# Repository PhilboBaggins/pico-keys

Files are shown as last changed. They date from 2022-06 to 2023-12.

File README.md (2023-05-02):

PicoKeys
========

A small macro keyboard using a [RPi Pico](https://www.raspberrypi.com/products/raspberry-pi-pico/). Originally made to help someone that had been in a car accident and had (hopefully temporary) limited use of her fingers. The original problem was that her work laptop required pressing CTRL-ALT-DELETE to login, which she couldn't do with only 2 working fingers. This board solved that with 1 key and left 15 more for other conveniences.

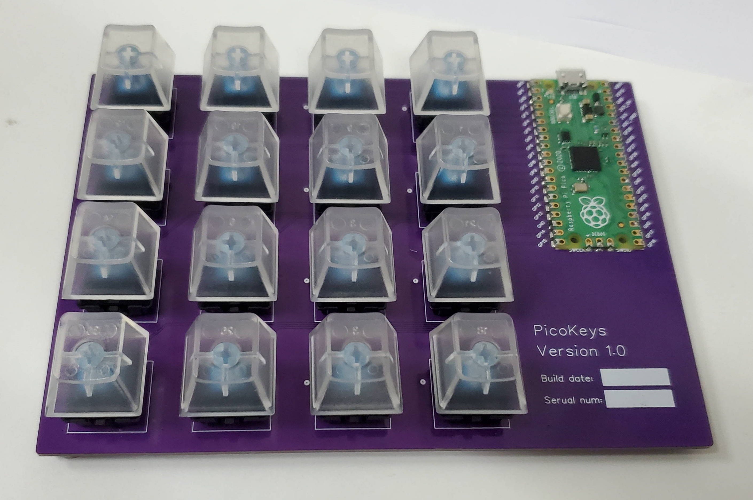
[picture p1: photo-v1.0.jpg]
Photo of assembled v1.0 board

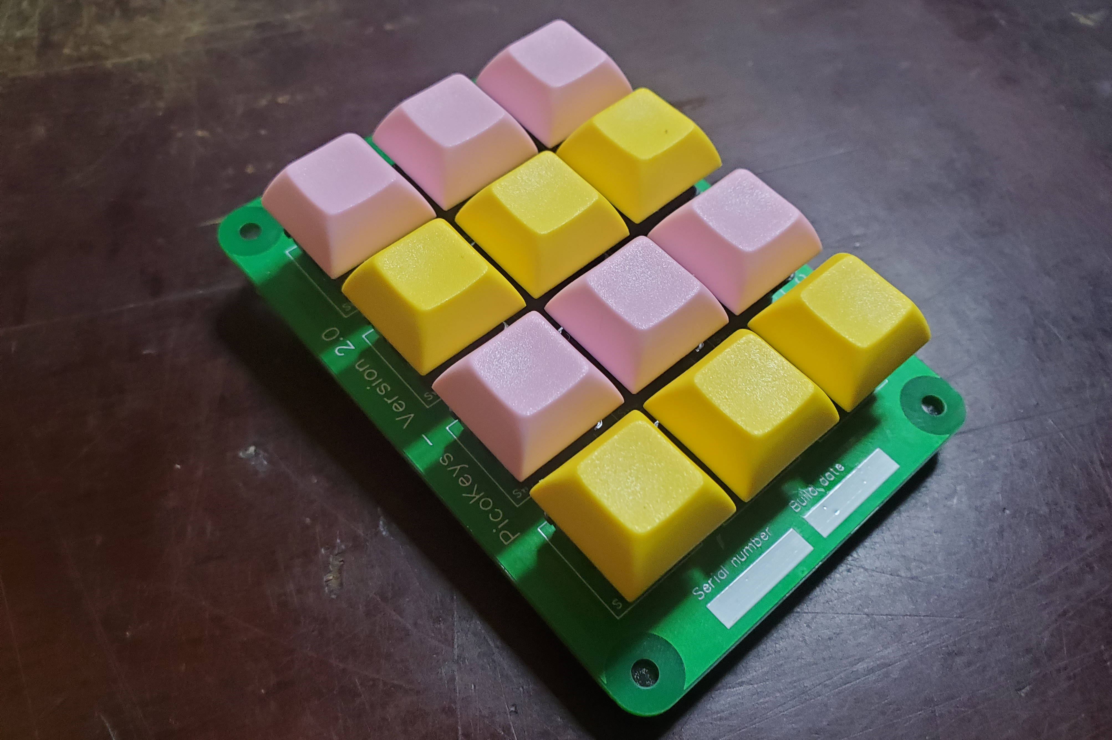
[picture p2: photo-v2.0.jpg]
Photo of assembled v2.0 board


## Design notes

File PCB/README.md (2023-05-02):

PicoKey PCB
===========

A small macro keyboard using a [RPi Pico](https://www.raspberrypi.com/products/raspberry-pi-pico/).

| Version 1.0 | Version 2.0 |
| --- | --- |
| Top of v1.0 board | Top of v2.0 board |
| Bottom of v1.0 board | Bottom of v2.0 board |
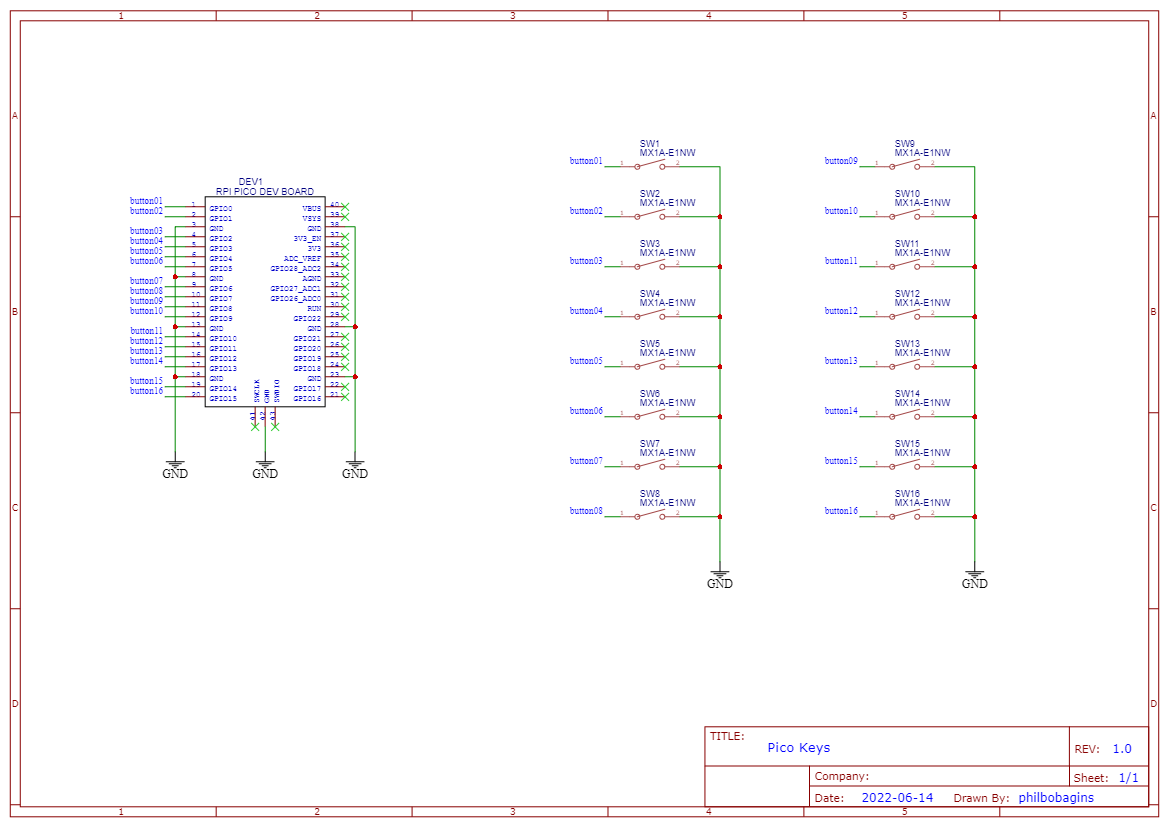
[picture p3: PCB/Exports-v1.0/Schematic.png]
Schematic for v1.0 board
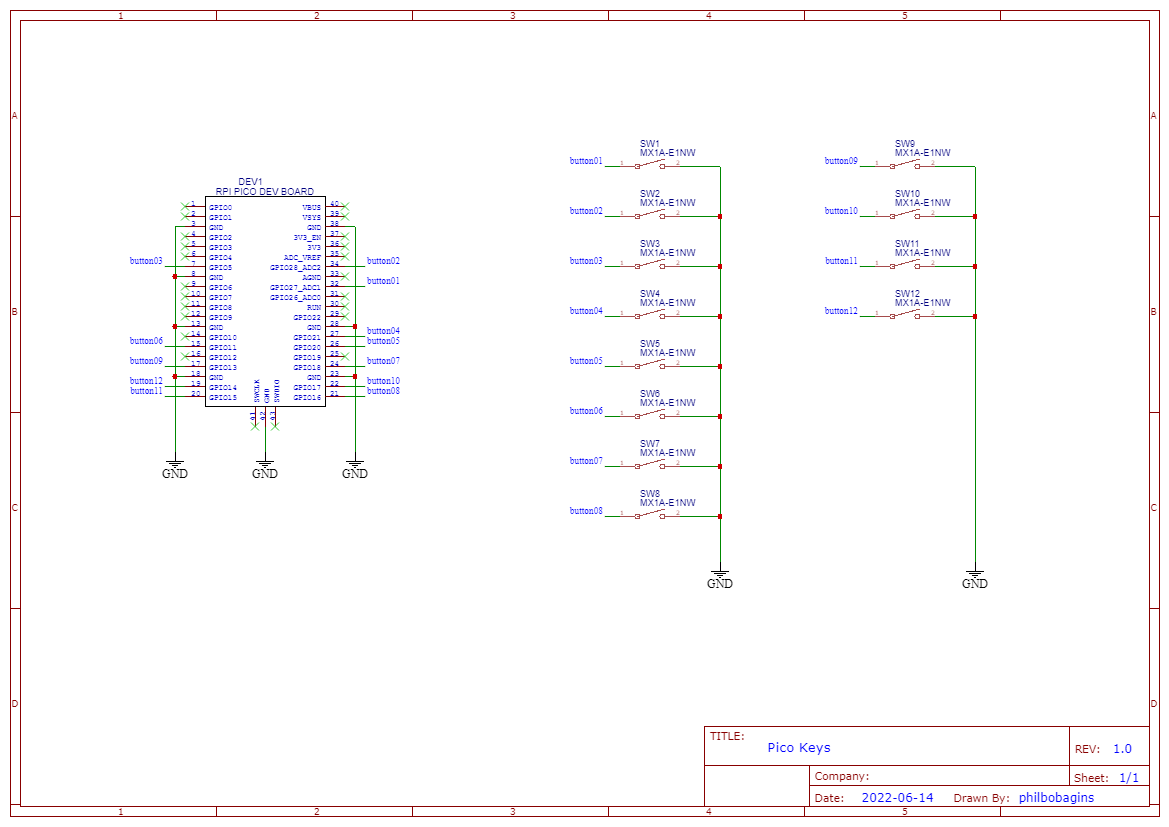
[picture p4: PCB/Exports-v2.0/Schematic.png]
Schematic for v2.0 board
|  |  |
| Photo of assembled v1.0 board | Photo of assembled v2.0 board |

Components
----------

The standard RPi Pico:

* Official website: <https://www.raspberrypi.com/products/raspberry-pi-pico/>
* DigiKey: <https://www.digikey.com/en/products/detail/raspberry-pi/SC0915/13624793>

Version 2.x board require 2 sets of 1x20 0.1" male headers to mount the RPi Pico. On version 1.x boards, the RPi Pico can be mounted on headers or just soldered down surface mount style.

Any of the following key switches will work:

* Any Cherry MX key switches without LEDs
* TODO: Check if [Akko CS](https://www.pccasegear.com/products/58938/akko-cs-crystal-blue-switches-45-pack) key switches work
* TODO: Check if [Akko POM](https://www.pccasegear.com/products/58934/akko-pom-brown-switches-45-pack) key switches work
* TODO: Check if [Akko x TTC Demon](https://www.pccasegear.com/products/55511/akko-x-ttc-demon-switches-10-pack) key switches work
* TODO: Check if [Gateron MX](https://www.pccasegear.com/products/47910/gateron-mx-switches-blue-120-pack) key switches work
* TODO: Check if [Glorious Forge Fox](https://www.pccasegear.com/products/58769/glorious-forge-fox-switches-120-pack-lubed) key switches work
* TODO: Check if [Glorious Lynx](https://www.pccasegear.com/products/55150/glorious-lynx-switches-36-pack) key switches work
* TODO: Check if [Glorious Panda](https://www.pccasegear.com/products/51561/glorious-panda-switches-36-pack) key switches work
* TODO: Check if [Kailh Box Black](https://www.pccasegear.com/products/51695/kailh-box-black-switches-120-pack) key switches work
* TODO: Check if [Kailh Speed Bronze](https://www.pccasegear.com/products/51696/kailh-speed-bronze-switches-120-pack) key switches work
* TODO: Check if [Mountain Linear Speed](https://www.pccasegear.com/products/57926/mountain-linear-speed-switches-110-pack-lubed) key switches work

Optional: Caps for key switches - TODO: Provide some examples

Optional: Stick on padded bumpers (e.g. <https://www.digikey.com/en/products/filter/bumpers-feet-pads-grips/570>)

Assembly instructions
---------------------

For v1.x boards:

1. Solder key switches and RPi Pico in any order
2. Clean flux
3. Press on key caps (optional)
4. Add stick on padded bumpers to bottom of board (optional)

For v2.x boards, the order things are soldered is a bit more important because of the way the RPi Pico and key switches overlap:

1. Solder 2 sets of 1x20 0.1" male headers to the underside of the board
   1. Recommend placing the RPi Pico over the headers to help keep them aligned but do not solder the RPi Pico yet
2. Clean flux
3. Solder all the key switches
4. Clean flux
5. Solder the RPi Pico to the 0.1" male headers
6. Clean flux
7. Trim the the 0.1" male headers poking through the RPi Pico
8. Press on key caps (optional)
9. Add stand-offs or stick on padded bumpers to bottom of board (optional)

Licence
-------

Copyright © 2022 Phil Baldwin

This work is licensed under a Creative Commons Attribution-ShareAlike 4.0 International License.

You should have received a copy of the license along with this work. If not, see <http://creativecommons.org/licenses/by-sa/4.0/>.

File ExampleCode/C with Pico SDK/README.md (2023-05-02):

# PicoKeys example using RPi Pico C SDK

Example code for use on a PicoKeys board using the Raspberry Pi Pico's C/C++ SDK.

The Pico becomes at USB HID device that sends keyboard key presses when PicoKeys buttons are pressed.

## Building

### Building on Linux

    PICO_SDK_PATH="path/to/pico-sdk"
    mkdir build
    cd build
    #cmake -DCMAKE_BUILD_TYPE=Debug ..
    cmake ..
    make

### Building on Windows with NMake

    set PICO_SDK_PATH="C:/path/to/pico-sdk"
    mkdir build
    cd build
    #cmake -G "NMake Makefiles" -DCMAKE_BUILD_TYPE=Debug  ..
    cmake -G "NMake Makefiles" ..
    nmake

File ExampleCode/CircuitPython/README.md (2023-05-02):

PicoKeys CircuitPython example program
======================================

Example program for using the PicoKeys board with [CircuitPython](https://circuitpython.org/) 7.x, based on the code from Adafruit's [DIY Pico Mechanical Keyboard with Fritzing and CircuitPython](https://learn.adafruit.com/diy-pico-mechanical-keyboard-with-fritzing-circuitpython/code-the-pico-keyboard) project.

Installation instructions
-------------------------

1. Install CiruitPython version 7.x:
    1. Download CiruitPython for the Raspberry Pi Pico from circuitpython.org](https://circuitpython.org/board/raspberry_pi_pico/)
    2. Start with your Pico unplugged from USB. Hold down the BOOTSEL button, and while continuing to hold it (don't let go!), plug the Pico into USB. Continue to hold the BOOTSEL button until the RPI-RP2 drive appears!
    3. If the drive does not appear, unplug your Pico and go through the above process again.
    4. A lot of people end up using charge-only USB cables and it is very frustrating! So make sure you have a USB cable you know is good for data sync.
    5. Once you see a new disk drive appear called RPI-RP2, drag the adafruit_circuitpython_etc.uf2 file to RPI-RP2.
    6. The RPI-RP2 drive will disappear and a new disk drive called CIRCUITPY will appear.
2. Copy the code.py and lib folder to your CIRCUITPY drive:
    * NOTE: This will replace the current code.py, as well as the lib folder and its contents. Back up any desired code before copying these files!
3. Unplug the RPi Pico from your computer and then plug it back in
   * The CIRCUITPY drive will show up again but you can just close and ignore it now

Copyright and licence info
--------------------------

Copyright © 2021, 2022 Phil Baldwin and John Park for Adafruit Industries

Code licensed under the MIT license (see [LICENSE.txt](LICENSE.txt) or <http://opensource.org/licenses/MIT>).

Code and installation instructions based on [Adafruit example program](https://learn.adafruit.com/diy-pico-mechanical-keyboard-with-fritzing-circuitpython/code-the-pico-keyboard) by John Park.

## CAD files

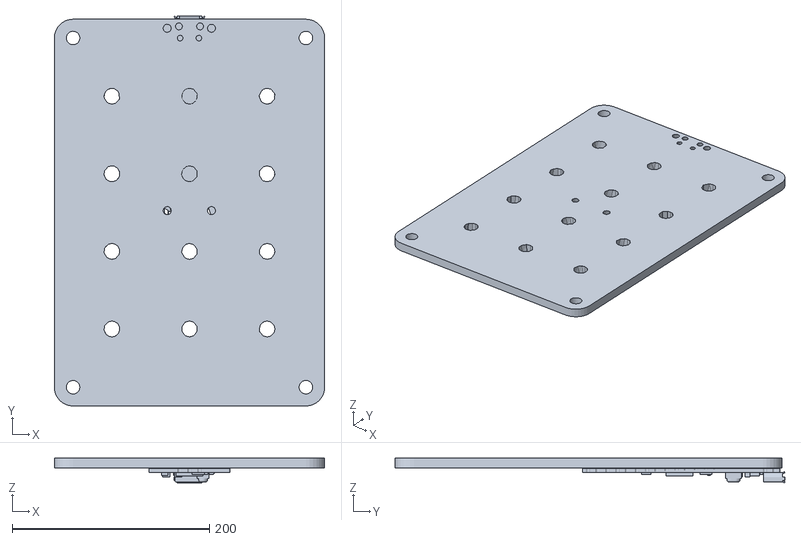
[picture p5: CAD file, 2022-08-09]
PCB/Exports-v2.0/3D-model/OBJ_PCB_PicoKeys.obj
274.4 x 395.7 x 25.3

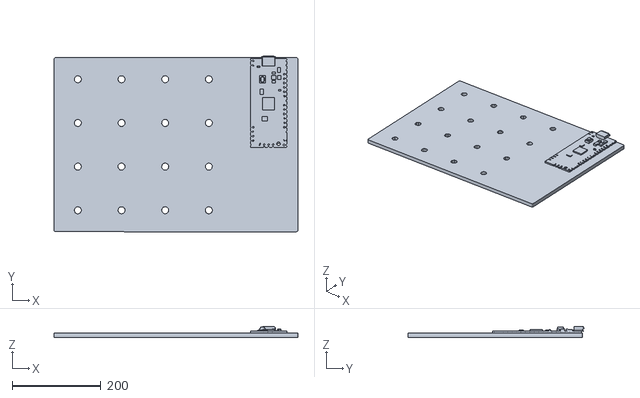
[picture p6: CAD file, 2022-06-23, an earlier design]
PCB/Exports-v1.0/3D-model/OBJ_PCB_PicoKeys.obj
550.0 x 395.7 x 25.3

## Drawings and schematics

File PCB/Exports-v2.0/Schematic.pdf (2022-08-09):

## RPI PICO DEV BOARD

## DEV1

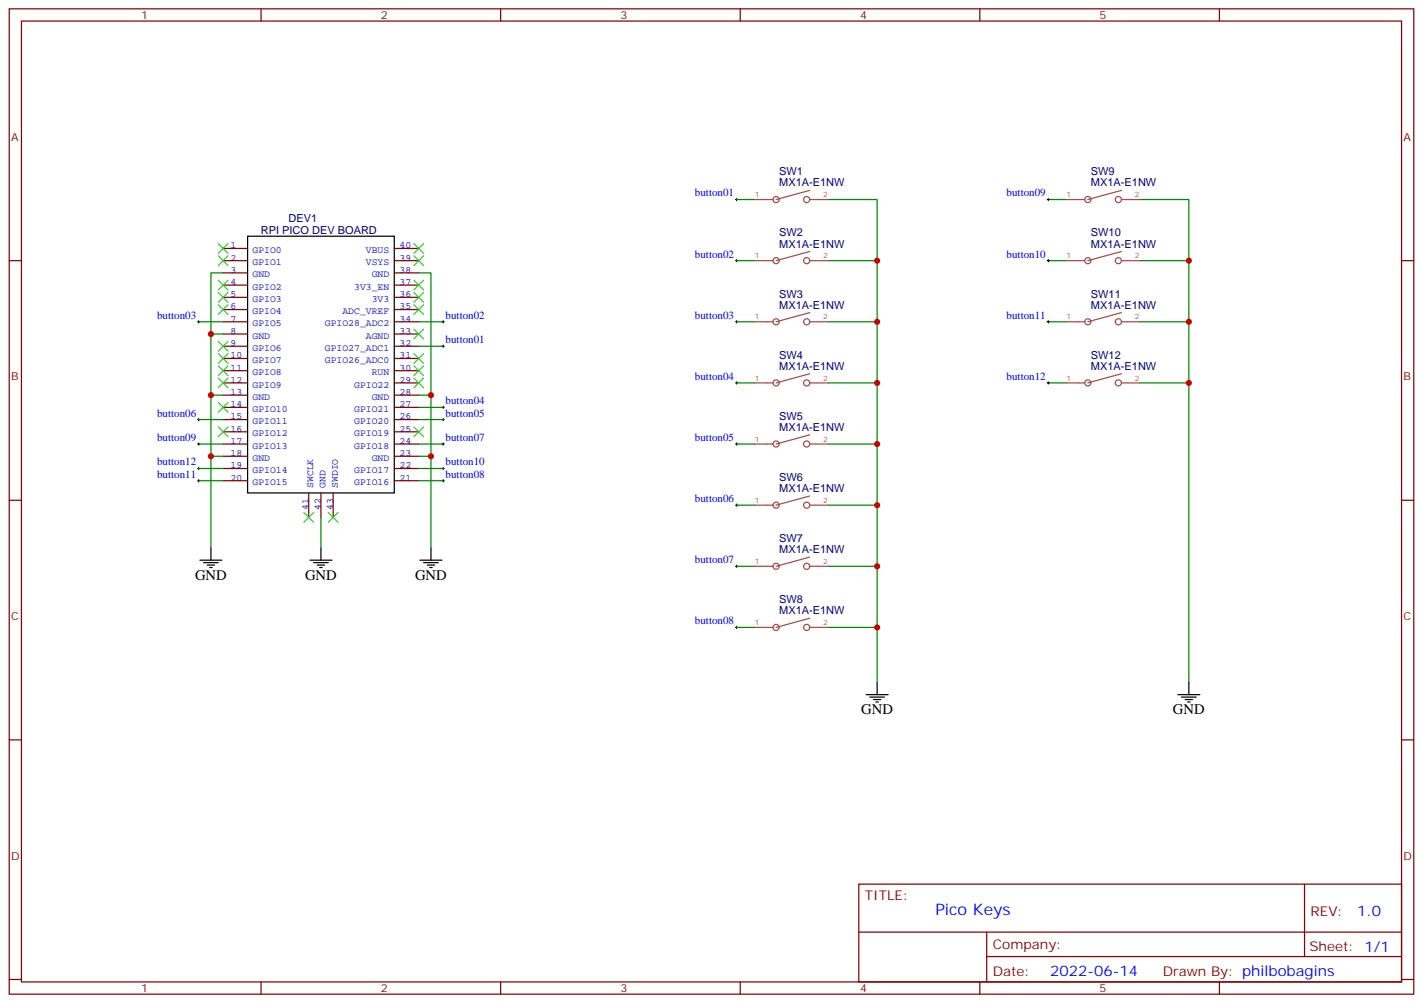
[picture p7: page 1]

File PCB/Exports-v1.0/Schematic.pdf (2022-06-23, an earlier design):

## RPI PICO DEV BOARD

## DEV1

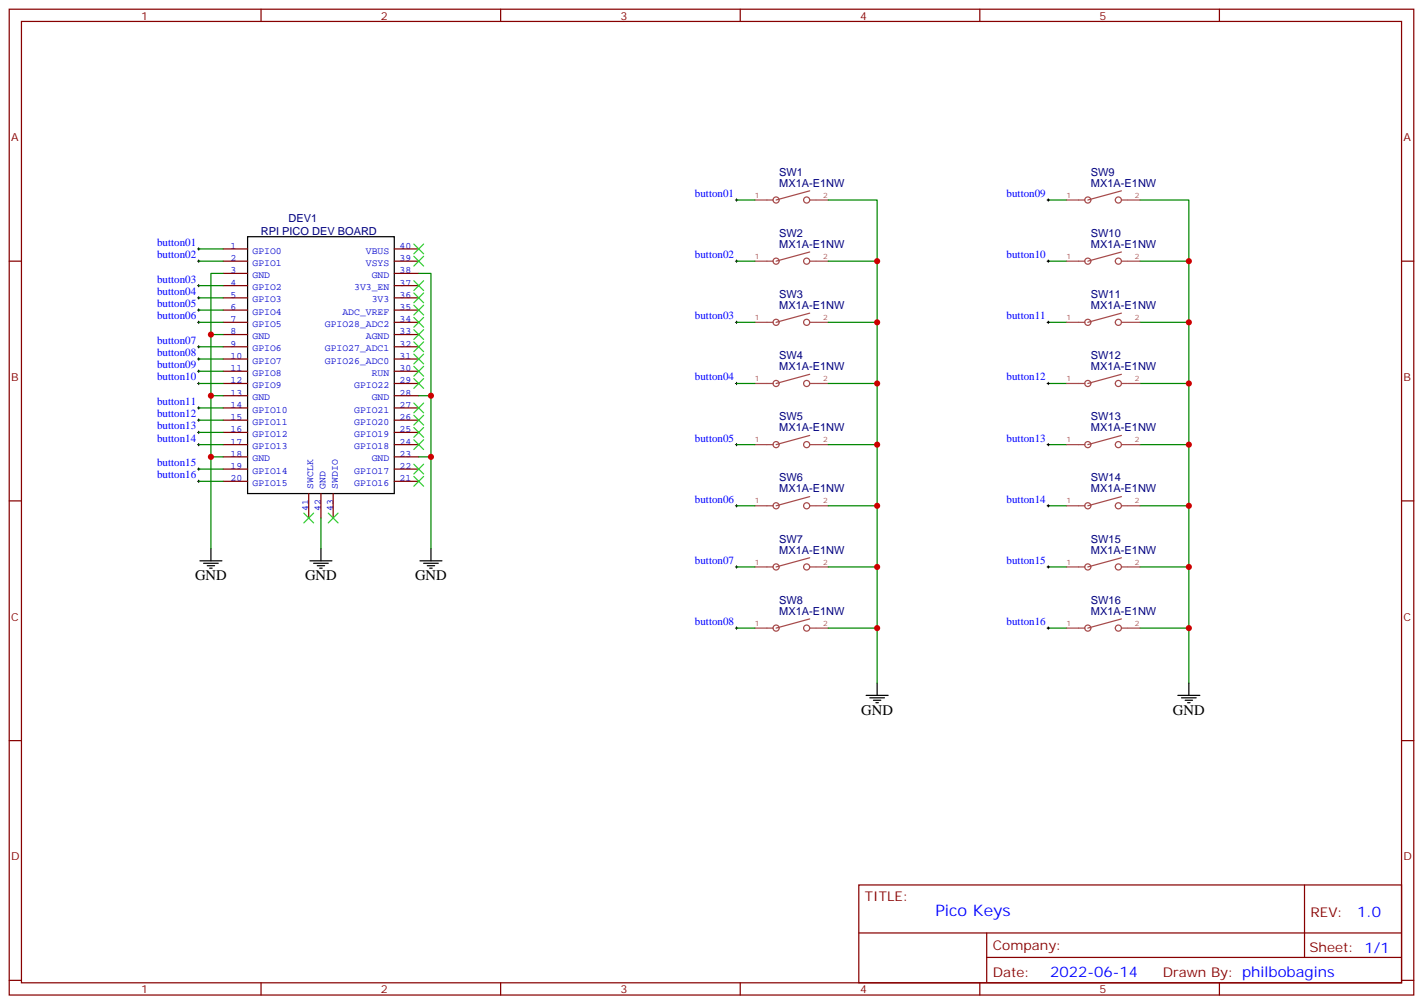
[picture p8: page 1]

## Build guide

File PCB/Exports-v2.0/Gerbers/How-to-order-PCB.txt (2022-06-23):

How to Order PCB

Please refer to:
https://docs.easyeda.com/en/PCB/Order-PCB

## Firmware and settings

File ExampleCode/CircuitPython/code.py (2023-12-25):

# SPDX-FileCopyrightText: 2021 John Park for Adafruit Industries
# SPDX-License-Identifier: MIT
# RaspberryPi Pico RP2040 Mechanical Keyboard

import time
import board
from digitalio import DigitalInOut, Direction
import usb_hid
from adafruit_hid.keyboard import Keyboard
from adafruit_hid.keyboard_layout_us import KeyboardLayoutUS
from adafruit_hid.keycode import Keycode
from adafruit_hid.consumer_control import ConsumerControl
from adafruit_hid.consumer_control_code import ConsumerControlCode
from button_checker import ButtonChecker, PRESSED, RELEASED
from pin_map import pins

print("---Pico Keys---")

led = DigitalInOut(board.LED)
led.direction = Direction.OUTPUT
led.value = True
LED_BLINK_INTERVAL = 0.5
ledBlinkTime = time.monotonic() + LED_BLINK_INTERVAL

kbd = Keyboard(usb_hid.devices)
cc = ConsumerControl(usb_hid.devices)
layout = KeyboardLayoutUS(kbd)

MEDIA = 1
KEY = 2
FUNC = 3

def loginSequence():
    layout.write('!!!!! USERNAME HERE !!!!!')
    time.sleep(0.1)  # Seconds

    kbd.press(Keycode.TAB)
    time.sleep(0.1)  # Seconds
    kbd.release(Keycode.TAB)
    time.sleep(0.1)  # Seconds

    layout.write('!!!!! PASSWORD HERE !!!!!')
    time.sleep(0.1)  # Seconds

    kbd.press(Keycode.ENTER)
    time.sleep(0.1)  # Seconds
    kbd.release(Keycode.ENTER)
    time.sleep(0.1)  # Seconds

keymap = {
    (0):  (KEY, (Keycode.CONTROL, Keycode.ALT, Keycode.DELETE)),
    (1):  (KEY, (Keycode.CONTROL, Keycode.ALT, Keycode.DELETE)),
    (2):  (MEDIA, ConsumerControlCode.VOLUME_DECREMENT),
    (3):  (MEDIA, ConsumerControlCode.VOLUME_INCREMENT),

    (4):  (FUNC, loginSequence),
    (5):  (KEY, [Keycode.B]),
    (6):  (KEY, [Keycode.C]),
    (7):  (KEY, [Keycode.D]),

    (8):  (KEY, [Keycode.E]),
    (9):  (KEY, [Keycode.F]),
    (10): (KEY, [Keycode.G]),
    (11): (KEY, [Keycode.H]),

    # Mot available on v2.x boards (keymap below will be ignored)
    (12): (FUNC, lambda: layout.write('Hello world')),
    (13): (FUNC, lambda: layout.write('Hello world')),
    (14): (FUNC, lambda: layout.write('Hello world')),
    (15): (FUNC, lambda: layout.write('Hello world')),
}

buttonChecker = ButtonChecker(pins)

while True:
    for button, state in buttonChecker.check_all():
        try:
            actionType = keymap[button][0]
            actionArgs = keymap[button][1]
            if state == PRESSED:
                if actionType == KEY:
                    kbd.press(*actionArgs)
                elif actionType == FUNC:
                    actionArgs()
                elif actionType == MEDIA:
                    cc.send(actionArgs)
            elif state == RELEASED:
                if actionType == KEY:
                    kbd.release(*actionArgs)
        except ValueError:  # deals with six key limit
            pass

    now = time.monotonic()
    if now > ledBlinkTime:
        ledBlinkTime = now + LED_BLINK_INTERVAL
        led.value = not led.value

    time.sleep(0.01)  # debounce

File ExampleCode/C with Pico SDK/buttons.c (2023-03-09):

#include <buttons.h>
#include "hardware/gpio.h"
#include <stdbool.h>

#if BOAD_MAJOR_VERSION == 1
    const int BUTTON_PINS[NUM_BUTTONS] = { 0, 1, 2, 3, 4, 5, 6, 7, 8, 9, 10, 11, 12, 13, 14, 15 };
#elif BOAD_MAJOR_VERSION == 2
    const int BUTTON_PINS[NUM_BUTTONS] = { 27, 28, 5, 21, 20, 11, 18, 16, 13, 17, 15, 14 };
#else
    #error Invalid board version selected
#endif

void buttons_init()
{
    for (int buttonIdx = 0; buttonIdx < NUM_BUTTONS; buttonIdx++)
    {
        const int gpioNumber = BUTTON_PINS[buttonIdx];
        gpio_init(gpioNumber);
        gpio_set_dir(gpioNumber, GPIO_IN);
        gpio_pull_up(gpioNumber);
    }
}

enum BUTTON_STATE buttonRead(int buttonIdx)
{
    static bool prevBtnStates[NUM_BUTTONS] = { false };

    const int gpioNumber = BUTTON_PINS[buttonIdx];
    const bool prevState = prevBtnStates[buttonIdx];
    const bool currentState = gpio_get(gpioNumber);
    prevBtnStates[buttonIdx] = currentState;

    if (!prevState && currentState)
    {
        return BUTTON_RELEASED;
    }
    else if (prevState && !currentState)
    {
        return BUTTON_PRESSED;
    }
    else if (!prevState && !currentState)
    {
        return BUTTON_HELD_PRESSED;
    }
    else
    {
        return BUTTON_NOT_PRESSED;
    }
}

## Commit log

2022-06-23 Add PCB files
    [BOM.csv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]
2022-06-28 Simplify the main loop by moving button checking code to button_checker.py
2022-06-28 More sensible LED blinking rate
2022-06-28 Add ExampleCode/CircuitPython/{README.md, LICENSE.txt}
2022-06-28 Update name printout at beginning of CircuitPython example
2022-08-09 Redesign for v2.0 board
    * Not trying to maintain compatability with v1.0
    * Smaller board
    * Less than 100mmx100mm, so cheap to build with JLC PCB
    * More compact, fits on your desk nicer
    * Only 15 buttons
    * RPi Pico on bottom of board now
    * Fix spelling mistake on silkscreen
2022-08-09 Add v2.0 exports
    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
    [BOM.csv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]
2022-09-28 Allow CircuitPython example code to handle v2.x PCBs
2022-09-28 Include pictures of v2.x PCBs in PCB/README.md
2022-09-28 Add photo of assembled v1.0 board
2022-09-28 Add assembly instructions for PCB
2022-09-28 Add info of PCB components
2022-09-28 Add photo of assembled v1.x board to PCB/README.md
2022-10-01 Add photo of assembled v2.0 board
2023-01-28 Reencode BOM.csv to UTF-8
    [BOM.csv]
2023-01-28 Convert BOMs from tab separated to comma separated
    [BOM.csv]
2023-02-03 Let's start a "C with Pico SDK" example
2023-02-03 Generate example project skeleton with Pico Project Generator
2023-03-07 Clean up generated Pico SDK code
2023-03-07 Start README.md for Pico SDK example
2023-03-07 Add selected files from Pico dev_hid_composite example
    https://github.com/raspberrypi/pico-examples/tree/master/usb/device/dev_hid_composite
2023-03-09 Add code I used on another project, mostly cribed from Pico's HID example
2023-03-09 Check buttons and send keypresses
2023-05-02 Remove LED blinking from example code because it really has nothing to do with this board
2023-12-23 Fix loginSequence
    Release TAB and ENTER keys in loginSequence and improve formatting
    [code.py]
